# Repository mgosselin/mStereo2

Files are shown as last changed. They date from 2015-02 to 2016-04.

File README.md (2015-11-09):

# mStereo: revision 2

mStereo is a two-channel digital-to-analog converter (DAC) for audio. It is under active development.

## In this repository
    .
    ├── doc             # documents and media used in the README documentation
    ├── libraries       # kicad library files
    └── projects        # kicad project files
        ├── gerbers     # gerber files for PCB fabrication 
        └── bom         # bill of materials and supplementary information

## Using the contents of this repository

This repo is built and maintained with Linux users in mind.  Some contents are .pdf or plain text so the repo may be cloned and those files may be opened irrespective of the platform.  Users wishing to use the Kicad project and other Kicad files by cloning and/or forking the repo can do so in Linux: no support is implied for OSX or windows users (although generally, OSX users should experience no problems).  
    
## Scope

mStereo is intended to be used as a component in systems for playback of high-resolution digital audio stored on computers.

## Electrical Specifications

| Specification | Value | Unit |
| --- |:---: | ----- |
| +12 V supply current draw ** | 70 | mA |
| -12 V supply current draw ** | 69 | mA |
| +5 V supply current draw ** | 259 | mA |
| Output impedance *** | 20.3 | Ώ |
| Output DC voltage offset *** | ± 1 | mV |
| Output RMS voltage level at 0 dBFS *** | 4.000 | V |

**  _measured with each channel driving 100 Ώ resistive load_

*** _measured across + and - output terminals_

## Schematic

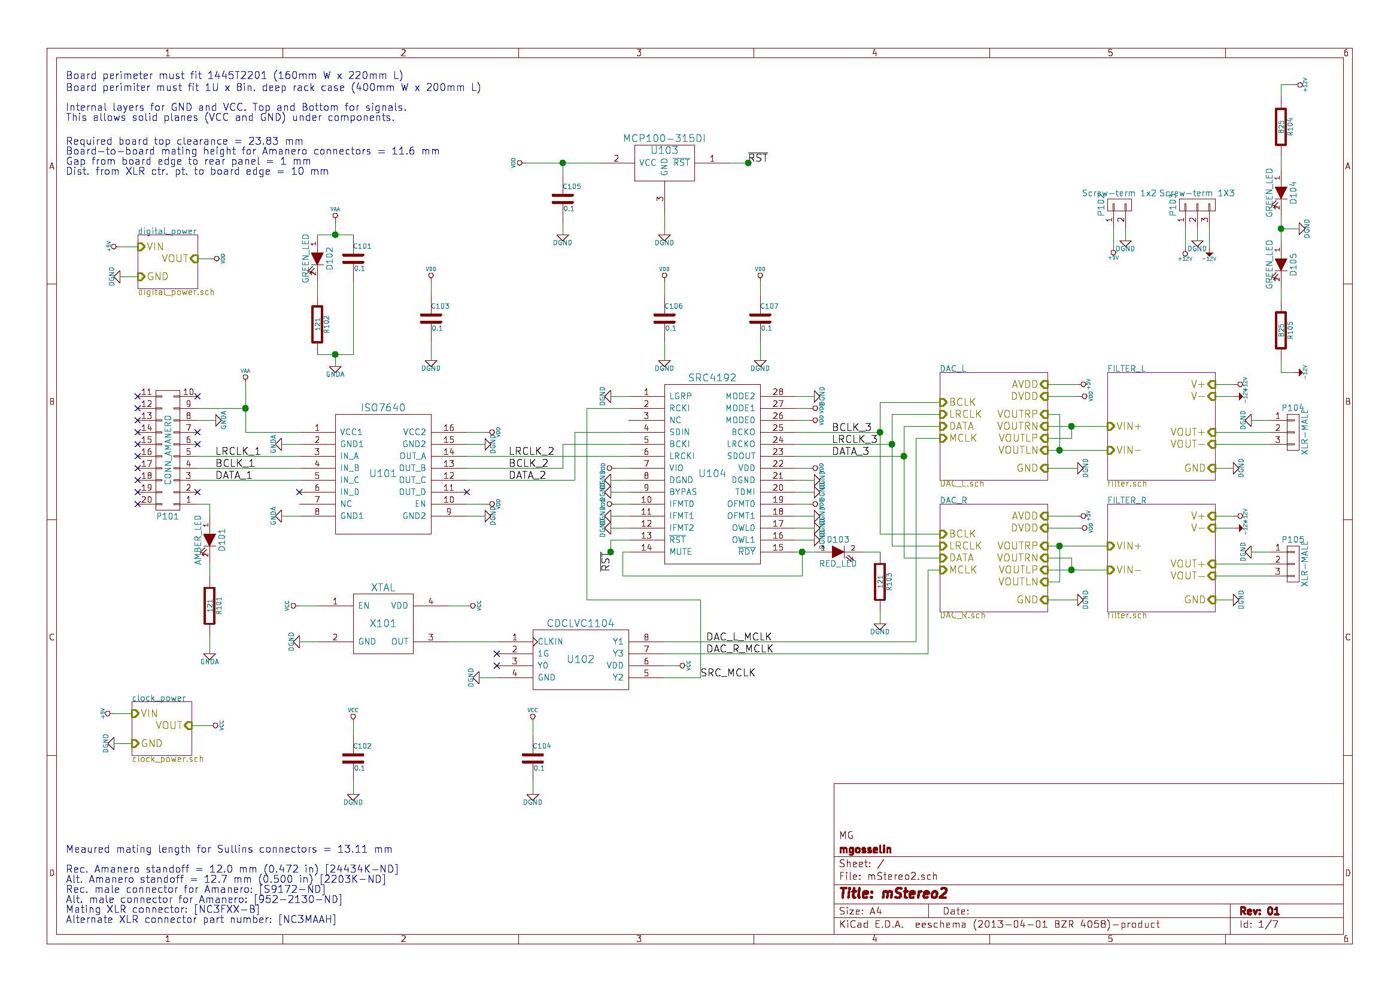
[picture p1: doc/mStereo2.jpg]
schematic


## Circuit Description

## Circuit Board

[Gerber files here](https://github.com/mgosselin/mStereo2/blob/master/projects/gerbers/).

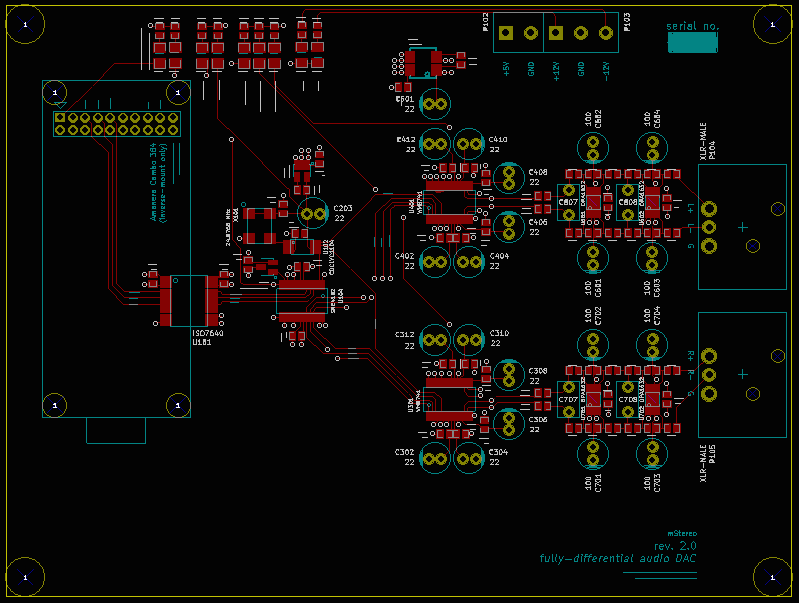
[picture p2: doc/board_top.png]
PCB_top


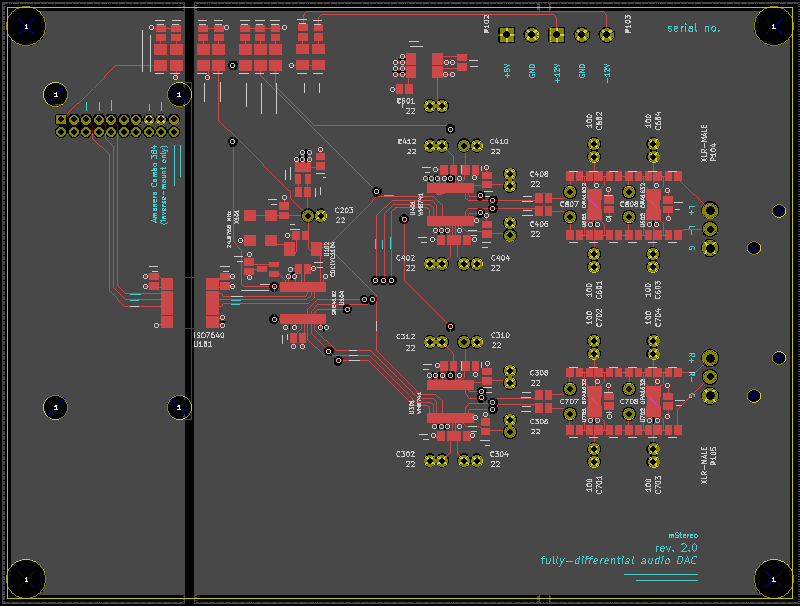
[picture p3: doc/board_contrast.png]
PCB_with_plates


## [BOM Page](https://github.com/mgosselin/mStereo2/blob/master/projects/bom)

## Assembly

## Ordering

At present, mStereo2 circuit boards (not populated) are available.  They may be obtained at-cost from me, by direct request.  

## History

mStereo is currently on revision 2.  Revision 1 is superceeded by revision 2, and while conceptually similar the hardware have little overlap.  Thus revision 1 documenation will no longer be updated and will remain accessible only by request.  

Since computers have become by far the most common way to exchange, store and playback audio recordings, the task remains to develop hardware to accompany computers and provide the best possible user experience. Since I am very serious about high-fidelity reproduction of audio recordings, developing my own hardware is challenging and rewarding on many fronts.

Practically, this means seeking the best possible hardware components (DAC ICs, oscillators, power supplies, etc.), integrating them, and ensuring their implementation permits their maximum specifications to be realized.

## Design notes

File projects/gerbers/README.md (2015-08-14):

# Gerber Files
All layers shown with edge-cut outline for easier viewing.

#### Copper Layers
Top Copper (signal traces, clock traces, clock power traces, component pads)
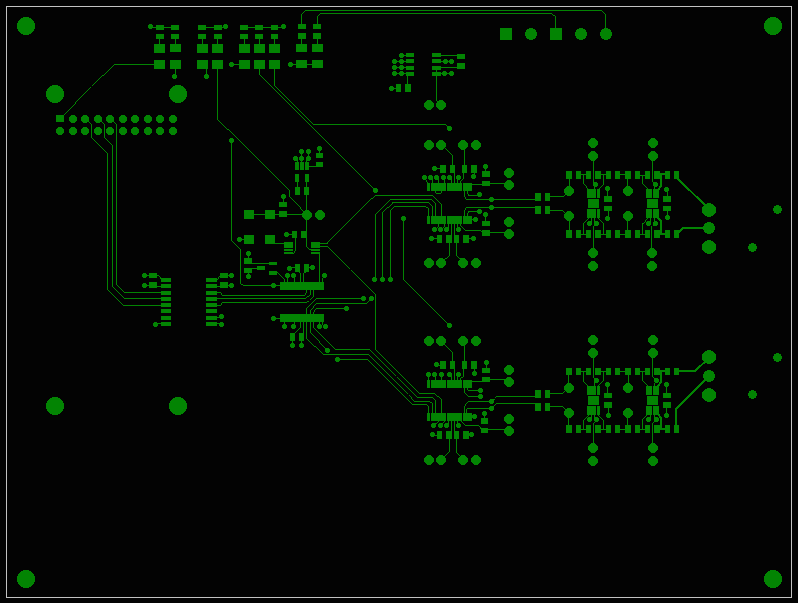
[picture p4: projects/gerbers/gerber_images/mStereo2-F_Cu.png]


Upper inner copper (planes [left-to-right]: USB ground, ground)
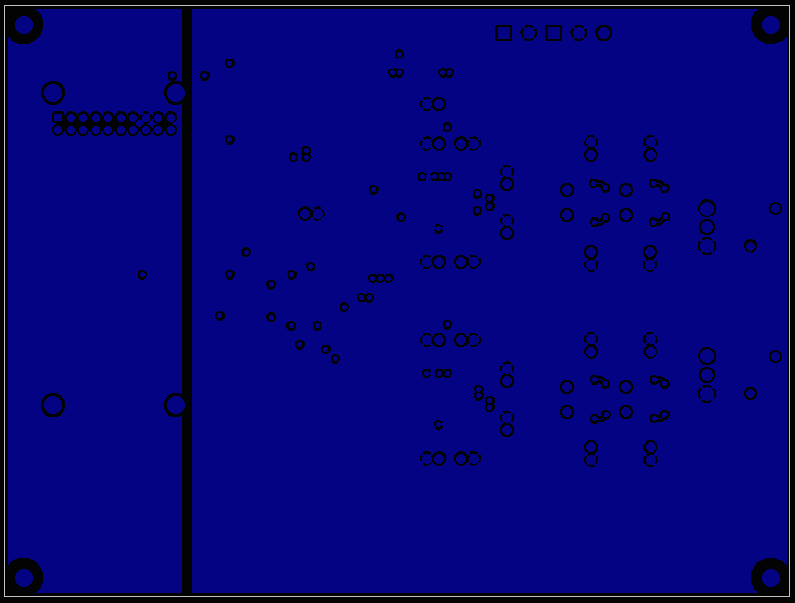
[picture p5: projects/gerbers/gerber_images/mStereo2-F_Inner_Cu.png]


Lower inner copper (planes [left-to-right]: USB power, +5VDC, +12VDC)
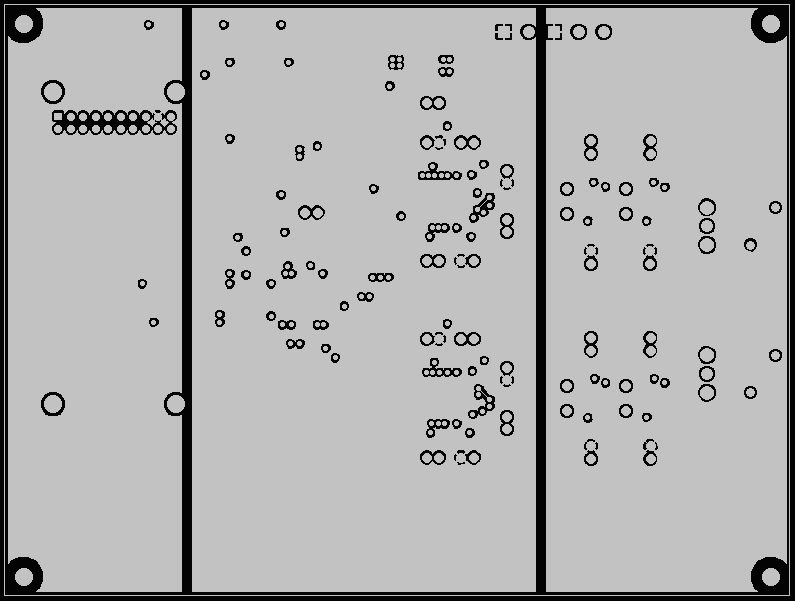
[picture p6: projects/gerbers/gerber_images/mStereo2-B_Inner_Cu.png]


Bottom copper (planes [left-to-right]: +3.3VDC, -12VDC)
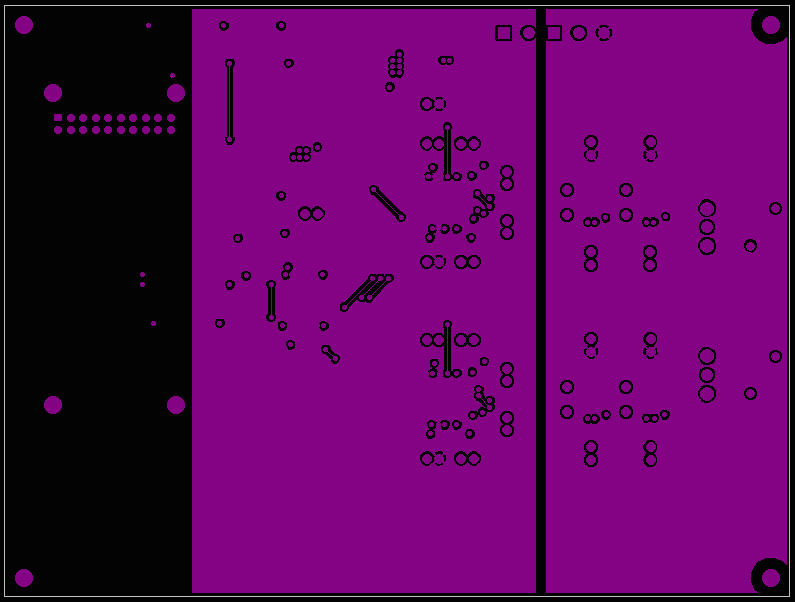
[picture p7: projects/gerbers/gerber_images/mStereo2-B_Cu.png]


#### Soldermask Layers
Top Soldermask
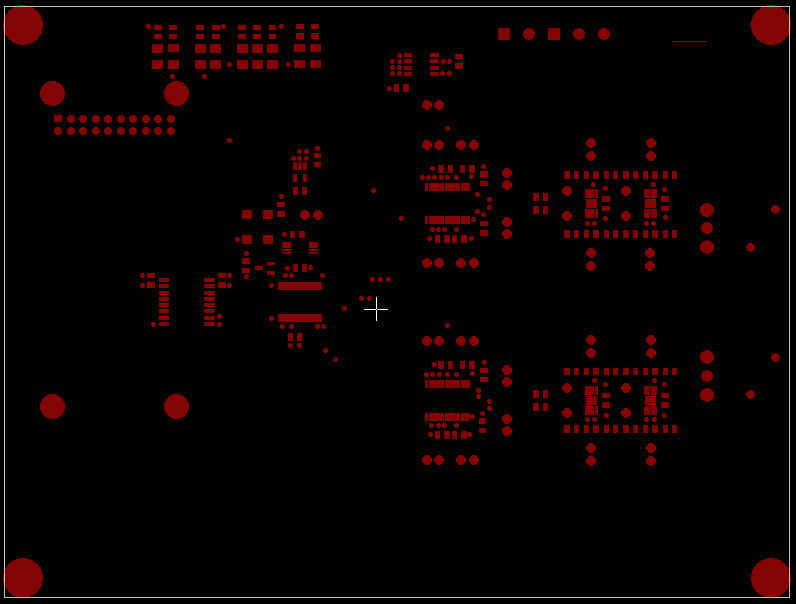
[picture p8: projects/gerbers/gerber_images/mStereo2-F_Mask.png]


Bottom Soldermask
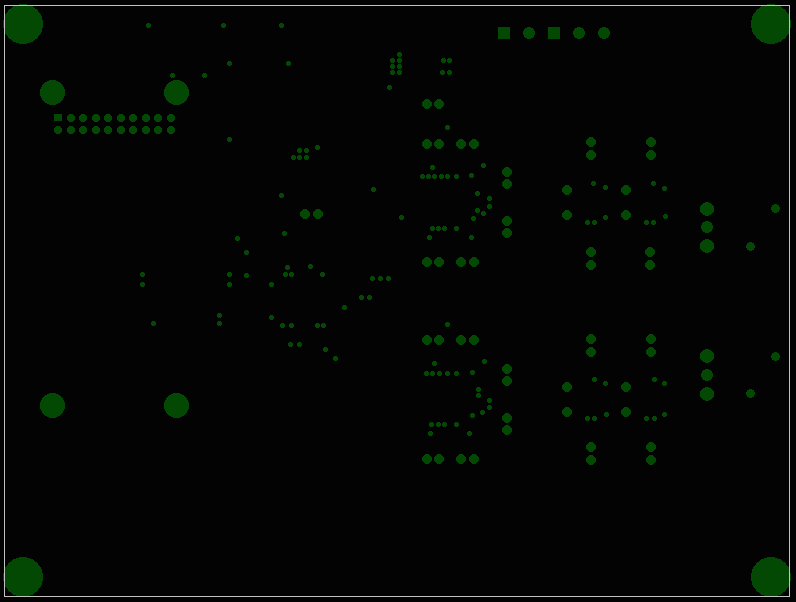
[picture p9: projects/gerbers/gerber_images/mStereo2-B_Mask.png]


#### Top Silkscreen Layer
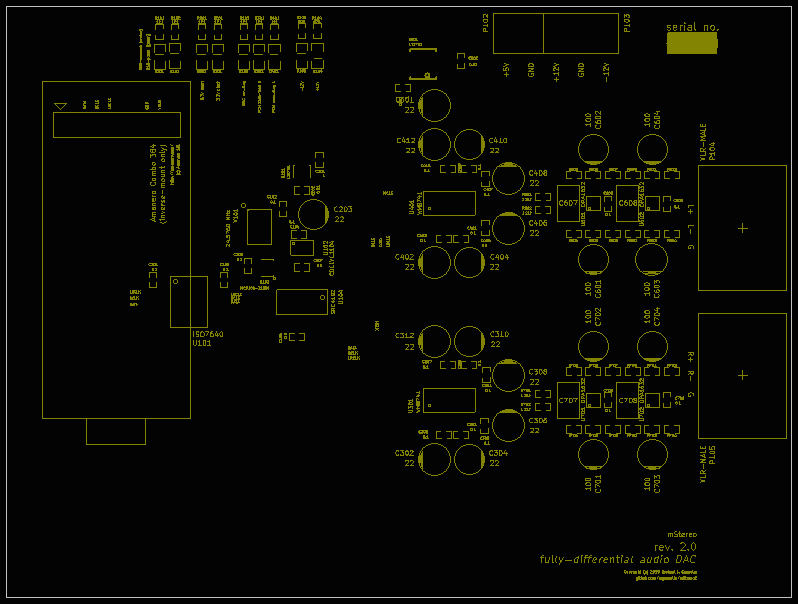
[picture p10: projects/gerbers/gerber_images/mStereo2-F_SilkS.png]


#### Drill holes
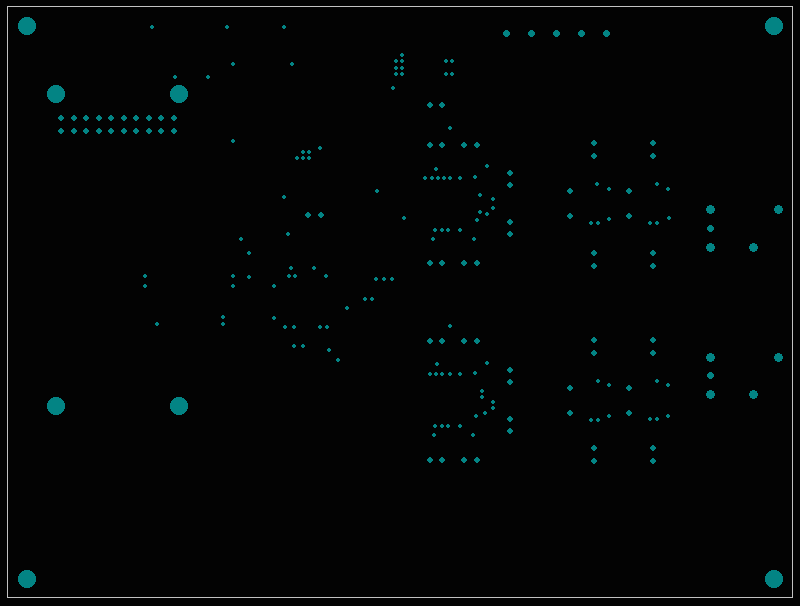
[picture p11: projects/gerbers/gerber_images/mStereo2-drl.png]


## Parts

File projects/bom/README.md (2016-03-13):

## BOM Notes

[The mStereo BOM](https://github.com/mgosselin/mStereo2/blob/master/projects/bom/mStereo2.csv) is best viewed in .CSV on a separate page.  Most vendors provide "BOM-upload tools" that prefer .CSV format.

#### 1. Circuit Board Support-Components
The BOM items are for populating the circuit board only.  Additional recommended hardware is as follows:
  
  1. A plastic insulation sheet to isolate the exposed pins on the bottom of the board (only needed if the PCB will be mounted less than 5mm from the chassis panel beneath it, and that chassis panel is metal).
  2. Standoffs
  3. Machine screws
  4. Hookup wire
  5. Heat shrink tubing

#### 2. Power supplies
A 12 VDC dual-rail regulated supply and a 5 VDC single-rail regulated supply are required.  The recommended supplies are the [AMB Labs](http://www.amb.org/audio/) [σ22](http://www.amb.org/audio/sigma22/) (a dual-rail linear regulated supply) and [σ11](http://www.amb.org/audio/sigma11/) (a single-rail linear regulated supply).  Both have been tested and are known to give excellent performance.  They are generally available on the [AMB Audio Shop](http://www.amb.org/shop/).  A slow-blow fuse rated for 200mA is recommended for these supplies.

Alternatives supplies may be used at your discretion.

BOMs for select [AMB Labs](http://www.amb.org/audio/) projects can be found [here](https://github.com/mgosselin/mStereo2/blob/master/projects/bom/AMB_Laboratories_Devices).

#### 3. Vendor Recommendations
#####Electronics:
  1. [Mouser](http://www.mouser.com/)
  2. [Digi-Key](http://www.digikey.com/)
  3. [Farnell](http://farnell.com/)

#####Mechanical Hardware:
  1. [McMaster-Carr](http://www.mcmaster.com/)
  2. [Amazon](http://www.amazon.com/)

#### 4. Output Filter / Buffer Design Considerations

#### 5. USB-to-I²S Conversion
As indicated in the [main README page](https://github.com/mgosselin/mStereo2), the mStereo circuit only accepts a valid I²S input as its source.  The circuit board is specifically designed around the [Combo 384](http://www.amanero.com/) module from Amanero SRL, which has a female USB type-A jack at its input.  Its mounting holes and connector fit properly with mStereo.  To use this module the following are needed:
 1. An Amanero Combo 384 module
 2. USB Cable, ideally with a ferrite choke such as Digi-Key part no. [1175-1417-ND](http://www.digikey.com/product-detail/en/102-1030-BL-F0100/1175-1417-ND/3782940)
 3. A USB panel mount jack, such as Neutrik [NAUSB-W-B](http://www.neutrik.com/en/multimedia/usb/nausb-w-b)*
 4. Standoffs (see table, below).  The board-to-board mating distance is 13.11 mm.
 5. M3 x 0.5 or #4-40 machine screws to go with standoffs

#####Combo 384 mounting information

| | Recommended Part No. | Alternate Part No. |
| --- |:---: | --- |
| Standoff (Female-Female) | [24434K-ND](http://www.digikey.com/product-search/en?keywords=24434K-ND) (12.0 mm, M3 thread)  | [2203K-ND](http://www.digikey.com/product-search/en?KeyWords=2203K-ND&WT.z_header=search_go) (0.500", 4-40 thread) |

| |  Female | Male |
| --- |:---: | --- |
| Connector |[S7078-ND](http://www.digikey.com/product-search/en?keywords=S7078-ND) ( _also found on the mStereo circuit board [BOM](https://github.com/mgosselin/mStereo2/blob/master/projects/bom/mStereo2.csv#L20)_ ) | [952-2130-ND](http://www.digikey.com/product-search/en?KeyWords=952-2130-ND&WT.z_header=search_go) |

**Ensure the USB cable and panel mount jack combination will work with the female USB-A-style jack on the Amanero Combo 384.*

#### 6. Enclosure and Mounting Considerations

  1. Hammond [1455Q1601](http://www.hammondmfg.com/pdf/1455Q1601.pdf) (PCB geometry and connector positioning fits this case perfectly, but without power supply)
  2. 1U standard rack-mount enclosures, from vendors such as [Hifi-2000](http://www.modushop.biz/site/index.php?route=product/category&path=20_27_61)
  3. Custom enclosures (DIY)

#####Key PCB and connector geometry

| Dimension | Quantity |
| --- |:---: |
| Board perimeter limits | 160 mm W x 120 mm L|
| Minimum clearance above top of PCB | 23.83 mm |
| Required gap from board edge to rear chassis panel | 1.0 mm |
| Required distance from XLR silkscreen centerpoint to chassis panel | 10 mm |
| Distance from XLR connector centerpoint to top of PCB | 12.5 mm |

#####XLR analog output connectors

The connectors listed below permit connection to the front or rear chassis panel with screws.  They should be fastened securely to the chassis panel so the force of inserting or pulling the mating XLR connector is not transferred to the PCB.  When received from the distributor, they come with straight, smooth-bore holes, which may be tapped with threads to permit easy attachment with machine screws to the chassis panel.  Use a UNC #4-40 tap or a metric size M3 tap and a tap wrench to tap threads in the appropriate plactes on these connectors.  

| Connector | Recommended Part No. | Alternate Part No. |
| --- | --- | --- |
| XLR chassis connector male |  Neutrik [NC3MAAH](http://www.neutrik.com/en/xlr/aa-series/nc3maah) | Neutrik [NC3MAAH-1](http://www.neutrik.com/en/xlr/aa-series/nc3maah-1) |
| Grounding Notes | _NOTE: with this connector, the PCB's signal ground plane (and therefore also the power supply ground) will connect to pin 1 only.  The signal ground plane will be isolated from the chassis panel and the mating connector.  It will ensure the chassis panel is connected to the mating connector shell for continuous sheilding._ |  _NOTE: with this connector the PCB's signal ground plane (and therefore also the power supply ground) will connect to the mating connector shell, the chassis panel, and pin 1, all at a common node._ |

The following female XLR cable connectors may be used to mate with the male chassis connectors on mStereo.  

| Connector | Recommended Part No. | Alternate Part No. |
| --- | --- | --- |
| XLR cable connector female | Neutrik [NC3FXX-B](http://www.neutrik.com/en/xlr/xx-series/nc3fxx-b) | Neutrik [NC3FXX](http://www.neutrik.com/en/xlr/xx-series/nc3fxx)|

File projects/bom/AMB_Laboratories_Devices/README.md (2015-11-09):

BOMs for select [AMB Labs](http://www.amb.org/audio/) projects, and others:
  * [ε24 power switch driver circuit](http://www.amb.org/audio/epsilon24/)
  * [σ22 regulated power supply](http://www.amb.org/audio/sigma22/)
  * Some support components for a Texas Instruments TPS7A4700-based power supply found on eBay

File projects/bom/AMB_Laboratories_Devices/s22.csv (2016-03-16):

Quantity | "Refs" | "Description" | "Supplier-PN" | "Manu-PN"
5 | R1 R2 R8 R9 R11 | RES 10.0K OHM 1/4W 1% AXIAL | 10.0KXBK-ND | MFR-25FBF52-10K
3 | R3 R16 R17 | RES 1.00K OHM 1/4W 1% AXIAL | 1.00KXBK-ND | MFR-25FBF52-1K
4 | R4 R5 R6 R7 | RES 100 OHM 1/4W 1% AXIAL | 100XBK-ND | MFR-25FBF52-100R
4 | R12 R13 R14 R15 | RES MO 2W .47 OHM 5% AXIAL | RSMF2JTR470CT-ND | RSMF2JTR470
6 | C1 C2 C3 C4 C16 C17 | CAP CER 220PF 100V 5% RADIAL | 399-4163-ND | C315C221J1G5TA
4 | C7 C8 C18 C19 | CAP FILM 1UF 10% 63VDC RADIAL | BC1622-ND | BFC237011105
4 | C5 C6 | CAP ALUM 1500UF 20% 50V RADIAL | 493-6907-ND | UHW1H152MHD6
5 | C9 C10 C13 C20 C21 | CAP ALUM 100UF 20% 63V RADIAL | 493-1936-ND | UPW1J101MPD
2 | C11 C12 | CAP ALUM 470UF 20% 63V RADIAL | 493-1948-ND | UPW1J471MHD
2 | C14 C15 | CAP FILM 3900PF 10% 400VDC RAD | BC1673-ND | BFC237051392
4 | D1 D2 D3 D4 | DIODE GEN PURP 200V 8A TO220AC | MUR820GOS-ND | MUR820G
1 | D5 | DIODE ZENER 12V 500MW DO35 | BZX55C12CT-ND | BZX55C12-TR
2 | D6 D7 | DIODE SCHOTTKY 40V 1A DO41 | 1N5819FSCT-ND | 1N5819
2 | CR1 CR2 | Current Regulator Diodes 2.2mA Curr Reg | 610-1N5306 | 1N5306
2 | CR3 CR4 | Current Regulator Diodes 4.7mA Curr Reg | 610-1N5314 | 1N5314
1 | LED | LED BLUE DIFF 3MM ROUND T/H | 751-1092-ND | TLHB4400
6 | Q1 Q3 Q4 Q9 Q10 Q12 | TRANS NPN 65V 0.1A TO-92 | BC546BTACT-ND | BC546BTA
6 | Q2 Q5 Q6 Q7 Q8 Q11 | TRANS PNP 65V 0.1A TO-92 | BC556BTACT-ND | BC556BTA
2 | Q13 Q14 | MOSFET N-CH 55V 17A TO-220AB | IRFZ24NPBF-ND | IRFZ24NPBF
2 | Q15 Q16 | MOSFET P-CH 55V 19A TO-220AB | IRF9Z34NPBF-ND | IRF9Z34NPBF
2 | - | CONN TERM BLOCK 3POS 5.08MM PCB | 277-1248-ND | 1729131
1 | - | CONN TERM BLOCK 2POS 5.08MM PCB | 277-1249-ND | 1729144
1 | - | XFRMR TOROIDAL 25VA CHAS MOUNT | 1295-1088-ND | 62063
1 | - | MOD PWR INLET COMPACT FILTER 10A | 817-1915-ND | FN281-10-06
4 | - | BOARD LEVEL HEATSINK 1-inch TO-220 | HS404-ND | 529702B02500G
4 | - | MOUNTING KIT TO-220 | HS417-ND | 4880G

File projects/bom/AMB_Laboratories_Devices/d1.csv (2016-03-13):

Quantity | Refs | Description | Supplier-PN | Manu-PN
2 | R1+ R1- | RES ARRAY 10 RES 1K OHM 11SIP | 4611X-101-102LF-ND | 4611X-101-102LF
2 | R2+ R2- | RES ARRAY 8 RES 47 OHM 9SIP | 4609X-101-470LF-ND | 4609X-101-470LF
2 | R5+ R5- | RES ARRAY 8 RES 47K OHM 9SIP | 4609X-101-473LF-ND | 4609X-101-473LF
2 | R3 R4 | miniature 1/8W resistor 3.3KΩ | S3.3KCACT-ND | RNMF14FTC3K30
2 | RS0L RS0R | Metal Film Resistors - Through Hole 1/10watt 1.4Kohms 1% 50ppm | 71-RN55C-F-1.4K | RN55C1401FB14
2 | RS1L RS1R | Metal Film Resistors - Through Hole 1/10watt 2.74Kohms 1% 50ppm | 71-RN55C-F-2.74K | RN55C2741FB14
2 | RS2L RS2R | Metal Film Resistors - Through Hole 1/10watt 5.11Kohms 1% 50ppm | 71-RN55C-F-5.11K | RN55C5111FB14
2 | RS3L RS3R | Metal Film Resistors - Through Hole 1/10watt 9.31Kohms 1% 50ppm | 71-RN55C9311F | RN55C9311FB14
2 | RS4L RS4R | Metal Film Resistors - Through Hole 1/10watt 15Kohms 1% 50ppm | 71-RN55C-F-15K | RN55C1502FB14
2 | RS5L RS5R | Metal Film Resistors - Through Hole 1/10watt 21Kohms 1% 50ppm | 71-RN55C-F-21K | RN55C2102FB14
2 | RS6L RS6R | Metal Film Resistors - Through Hole 1/10watt 24.3Kohms 1% 50ppm | 71-RN55C2432F | RN55C2432FB14
2 | RS7L RS7R | Metal Film Resistors - Through Hole 1/10watt 24.9Kohms 1% 50ppm | 71-RN55C-F-24.9K | RN55C2492FB14
2 | RP0L RP0R | Metal Film Resistors - Through Hole 1/10watt 422Kohms 1% 50ppm | 71-RN55C-F-422K | RN55C4223FB14
2 | RP1L RP1R | Metal Film Resistors - Through Hole 1/10watt 205Kohms 1% 50ppm | 71-RN55C2053F | RN55C2053FB14
2 | RP2L RP2R | Metal Film Resistors - Through Hole 1/10watt 97.6Kohms 1% 50ppm | 71-RN55C-F-97.6K | RN55C9762FB14
2 | RP3L RP3R | Metal Film Resistors - Through Hole 1/10watt 43.2Kohms 1% 50ppm | 71-RN55C-F-43.2K | RN55C4322FB14
2 | RP4L RP4R | Metal Film Resistors - Through Hole 1/10watt 16.5Kohms 1% 50ppm | 71-RN55C1652F | RN55C1652FB14
2 | RP5L RP5R | Metal Film Resistors - Through Hole 1/10watt 4.75Kohms 1% 50ppm | 71-RN55C-F-4.75K | RN55C4751FB14
2 | RP6L RP6R | Metal Film Resistors - Through Hole 1/10watt 649ohms 1% 50ppm | 71-RN55C-F-649 | RN55C6490FB14
2 | RP7L RP7R | Metal Film Resistors - Through Hole 1/10watt 16.2ohms 1% 50ppm | 71-RN55C-F-16.2 | RN55C16R2FB14
2 | RTL RTR | Metal Film Resistors - Through Hole 1/10watt 25.5Kohms 1% 50ppm | 71-RN55C2552F | RN55C2552FB14
2 | RGL RGR | RES 10 OHM 5W 5% AXIAL | PPC5W10.0CT-ND | AC05000001009JAC00
2 | C1 C3 | CAP POLYMER 470UF 20% 16V T/H | 565-3620-ND | APSG160ELL471MH08S
3 | C2+ C2- C4 | CAP CER 0.1UF 50V X7R RADIAL | 399-4264-ND | C320C104K5R5TA
2 | CGL CGR | CAP FILM 0.1UF 20% 300VAC RADIAL | P11116-ND | ECQ-U3A104MG
1 | L1 | FERRITE BEAD AXIAL LEAD 75 OHMS | 240-2438-1-ND | 28L0138-10R-10
2 | U1+ U1- | IC I/O EXPANDER I2C 8B 16DIP | 296-13106-5-ND | APCF8574AN
2 | U2+ U2- | TRANS 8NPN DARL 50V 0.5A 18DIP | ULN2803APG-ND | ULN2803APGCN
2 | LED+ LED- | LED BAR GRAPH 10SEG 590NM YLW | 754-1179-5-ND | DC10YWA
8 | K0-K7 | RELAY TELECOM DPDT 1A 4.5V | Z2143-ND | G6JU-2P-Y DC4.5
2 | - | CONN IC DIP SOCKET 16POS GOLD | ED90034-ND | 110-43-316-41-001000
2 | - | CONN IC DIP SOCKET 18POS GOLD | ED90035-ND | 110-43-318-41-001000
1 | J1 | CONN HEADER 6POS .100 R/A TIN | WM4304-ND | 0022053061
1 | J1 | CONN HOUS 6POS .100 W/RAMP/RIB | WM2004-ND | 0022013067
1 | J2 J3 | CONN HEADER 6POS .100 VERT TIN | WM4004-ND | 0022032061
1 | J2' J3' | CONN HEADER 6POS .100 STR TIN | WM8076-ND | 0901200126
1 | J2 J3 | Connector Receptacle 6 Position 0.100 (2.54mm) Tin Through Hole | WM4223-ND | 0901471106
1 | J4 | CONN HEADER 16POS .100 R/A TIN | 609-3356-ND | 68021-416HLF
1 | J5 | CONN RECEPT 16POS .100 RT/A DUAL | A34302-ND | 5-532956-2
2 | J4 J5 | [for ribbon cbl assly only] CONN HEADER 16POS R/A 10GOLD | MHE16E-ND | D2516-5002-AR
2 | J4 J5 | [for ribbon cbl assly only] CONN 16POS IDC SOCKET 10AU W/POL | MKC16E-ND | D89116-0131HK
2 | J4 J5 | [for ribbon cbl assly only] STRAIN RELIEF 16POS D89-SERIES | MESR16-ND | D3448-89116
1 | J4 J5 | [for ribbon cbl assly only] CBL RIBN 16COND 0.050 GRAY 5' | MC16G-5-ND | 3365/16 300SF
4 | INPUTL INPUTR OUTPUTL OUTPUTR | CONN HEADER 2POS .100 R/A TIN | WM4300-ND | 0022053021
4 | INPUTL INPUTR OUTPUTL OUTPUTR | CONN HOUS 2POS .100 W/RAMP/RIB | WM2000-ND | 0022013027
2 | INOUTL INOUTR | CONN HEADER 3POS .100 R/A TIN | WM4301-ND | 0022053031
2 | INOUTL INOUTR | CONN HOUS 3POS .100 W/RAMP/RIB | WM2001-ND | 0022013037
20 | - | CONN TERM FEMALE 22-30AWG TIN | WM1114-ND | 0008500114
1 | JP1A+ JP1B+ JP1C+ JP1A- JP1B- JP1C- JP2 JP3 | CONN HEADER .100 SINGL STR 36POS | S1011E-36-ND | PBC36SAAN
10 | - | CONN JUMPER SHORTING GOLD FLASH | S9001-ND | SPC02SYAN
4 | - | HEX STANDOFF M3 ALUMINUM 12MM | 36-24434-ND | 24434

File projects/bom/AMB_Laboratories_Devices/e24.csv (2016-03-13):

Quantity | "Refs" | "Description" | "Supplier-PN" | "Manu-PN"
1 | R1 | 470K 1/8W miniature resistor | S470KQCT-ND | CFM14JT470K
1 | R2 | 2.2MΩ 1/8W miniature resistor | S2.2MQCT-ND | CFM14JT2M20
1 | R3 | 2.2KΩ 1/8W miniature resistor | S2.2KQCT-ND | CFM14JT2K20
1 | R5 | 330KΩ 1/8W miniature resistor | S330KQCT-ND | CFM14JT330K
1 | R6 | 10KΩ 1/8W miniature resistor | S10KQCT-ND | CFM14JT10K0
1 | C1 | 470µF 25V electrolytic capacitor (8mm diameter 3.5mm lead pitch) | P12389-ND | EEU-FM1E471L
1 | C2 | 10µF 25V dipped tantalum capacitor (2.5mm lead pitch) | 399-3565-ND | T350E106K025AT
1 | C3 | 0.33µF 50V Z5U multilayer ceramic capacitor (2.5mm lead pitch) | 399-4299-ND | C320C334M5U5TA
1 | D1 | RECTIFIER BRIDGE 1.5A 100V WOG | W01G-E4/51GI-ND | W01G-E4/51
1 | D3 | 1N4148 small signal diode (DO-35) | 1N4148FS-ND | 1N4148
1 | Q2 | 2N3904 NPN transistor (TO-92) | 2N3904FS-ND | 2N3904BU
1 | Q3 | MOSFET N-CH 55V 18A TO-220AB | IRLZ24NPBF-ND | IRLZ24NPBF
1 | U1 | IC REG LDO 12V 1.5A TO220 | 497-12406-ND | L7812CV-DG
1 | - | RELAY GEN PURPOSE SPST 20A 12V | 255-4179-ND | JM1AN-ZTM-DC12V-F
1 | - | XFRMR TOROIDAL 1.6VA CHAS MOUNT | 1295-1018-ND | 62002
1 | - | SWITCH PUSH SPST-NO 0.05A 24V | 708-1453-ND | MPI002/TERM/WH

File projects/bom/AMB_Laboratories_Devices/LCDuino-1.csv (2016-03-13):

Quantity | "Refs" | "Description" | "Supplier-PN" | "Manu-PN"
1 | R1 | RES 10K OHM 1/4W 1% AXIAL | S10KCACT-ND | RNMF14FTC10K0
2 | R2 R3 | RES 1K OHM 1/4W 1% AXIAL | S1KCACT-ND | RNMF14FTC1K00
1 | VR1 | TRIMMER 10K OHM 0.5W TH | 490-2875-ND | PV36W103C01B00
1 | - | Potentiometers 16mm 100K ROTARY 3B TAPER | 688-RK16812MG099 | RK16812MG099
1 | C1 | CAP ALUM 100UF 20% 6.3V RADIAL | P958-ND | ECE-A0JKS101
4 | C2 C3 C4 C5 | CAP CER 0.1UF 50V X7R RADIAL | 399-4264-ND | C320C104K5R5TA
1 | C6 | CAP TANT 1UF 25V 10% RADIAL | 478-1834-ND | TAP105K025SCS
1 | Cs | 0.022F 5.5volts Radial Super Cap | 80-FR0H223ZF | FR0H223ZF
1 | U1 | Atmel ATmega328P-PU pre-flashed with bootloader and Volu-Master firmware | AMB audio shop | AMB audio shop
1 | U1' | IC MCU 8BIT 32KB FLASH 28DIP | ATMEGA328P-PU-ND | ATMEGA328P-PU
1 | U2 | IC RTC CLK/CALENDAR SER 8-DIP | DS1302+-ND | DS1302+
1 | U3 | IC I/O EXPANDER I2C 8B 18DIP | MCP23008-E/P-ND | MCP23008-E/P
1 | U4 | IC IR RCVR MOD 38KHZ DOME RADIAL | 751-1386-5-ND | TSOP34838
1 | U5 | IC MOTOR DRIVER PAR 16-DIP | 497-2936-5-ND | L293D
1 | X1 | CER RESONATOR 16.0MHZ | 490-1214-ND | CSTLS16M0X55-B0
1 | X2 | Crystal 32.7680kHz 20ppm 6pF 50 kOhm -10°C - 60°C Through Hole Radial | 728-1000-ND | VT200F-6PF20PPM
1 | LED13 | LED YELLOW DIFF 3MM ROUND T/H | TLHY4401-ND | TLHY4401
1 | LEDP | LED GRN DIFF 3MM ROUND T/H | 160-1142-ND | LTL-4231N
1 | SW1 | SWITCH TACTILE SPST-NO 0.05A 24V | SW400-ND | B3F-1000
1 | PWR/CFG switch | SWITCH PUSH SPST-NO 0.05A 24V | 708-1453-ND | MPI002/TERM/WH
1 | SSR | RELAY SSR 280VAC/5A3-32VDC ZC | CC1762-ND | CL240D05
1 | - | CONN IC DIP SOCKET 28POS TIN | ED90054-ND | 110-44-328-41-001000
1 | - | CONN IC DIP SOCKET 8POS TIN | ED90048-ND | 110-44-308-41-001000
1 | - | CONN IC DIP SOCKET 18POS TIN | ED90051-ND | 110-44-318-41-001000
1 | - | CONN IC DIP SOCKET 16POS TIN | ED90050-ND | 110-44-316-41-001000
2 | J1 J2 | CONN HEADER VERT .100 6POS 30AU | A26550-ND | 87220-6
2 | J1' J2' | Connector Receptacle 6 Position 0.100 Gold | A26418-ND | 534237-4
2 | J3 J4 | CONN HEADER 6POS .100 VERT TIN | WM4204-ND | 0022232061
2 | J3 J4 | CONN HOUS 6POS .100 W/RAMP/RIB | WM2004-ND | 0022013067
2 | J5 J6 | CONN HEADER 2POS .100 VERT TIN | WM4200-ND | 0022232021
2 | J5 J6 | CONN HOUS 2POS .100 W/RAMP/RIB | WM2000-ND | 0022013027
1 | J9 | CONN HEADER 5POS .100 VERT TIN | WM4203-ND | 0022232051
1 | J9 | CONN HOUS 5POS .100 W/RAMP/RIB | WM2003-ND | 0022013057
30 | - | CONN TERM FEMALE 22-30AWG TIN | WM1114-ND | 0008500114
1 | - | CABLE USB EMBD UART 3.3V .1inch HDR | 768-1015-ND | TTL-232R-3V3
1 | LCD | LCD MOD CHAR 2X16 WHT TRANSFL | NHD-0216K1Z-FSW-FBW-L-ND | NHD-0216K1Z-FSW-FBW-L
4 | SPACER | ROUND SPACER M3 BRASS 3MM | 952-1560-ND | R30-6010302
4 | STANDOFF | HEX STANDOFF M3 BRASS 13MM | 952-1504-ND | R30-3001302

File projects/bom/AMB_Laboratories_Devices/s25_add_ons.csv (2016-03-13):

Quantity | "Refs" | "Description" | "Supplier-PN" | "Manu-PN"
1 | R1 | RES 220 OHM 1/4W 1% AXIAL | S220CACT-ND | RNMF14FTC220R
1 | C2 | CAP ALUM 1000UF 20% 35V RADIAL | 493-6822-ND | UHW1V102MHD
1 | U1 | IC REG LDO 5V 1.5A TO220AB | 497-1404-5-ND | L4940V5
1 | U1' | IC REG LDO 5V 1A TO220-3 | LM7805CT-ND | LM7805CT
1 | - | XFRMR TOROIDAL 10VA CHAS MOUNT | 1295-1052-ND | 62041

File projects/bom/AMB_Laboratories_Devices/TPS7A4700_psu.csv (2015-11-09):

Quantity | "Refs" | "Description" | "Supplier-PN" | "Manu-PN"
3 | - | CONN TERM BLOCK 2POS 5.08MM PCB | 277-1247-ND | 1729128
3 | - | TERM BLOCK PCB 2POS 7.5MM GREEN | 277-6235-ND | 1717020
3 | - | HEAT SINK 15MM X 15MM X 9.5MM | ATS1263-ND | ATS-55150D-C2-R0

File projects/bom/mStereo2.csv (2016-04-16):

Quantity | "Supplier" | "Supplier-PN" | "Manu" | "Manu-PN" | "Refs"
1 | Digi-Key | LT1761ES5-3.3#TRMPBFCT-ND | Linear Technology | LT1761ES5-3.3#TRMPBF | U201
5 | Digi-Key | 160-1423-1-ND | Lite-On | LTST-C171GKT | D104 D105 D102 D201 D501
2 | Digi-Key | RNCP0805FTD825RCT-ND | Stackpole | RNCP0805FTD825R | R104 R105
1 | Digi-Key | LT1763CS8-3.3#PBF-ND | Linear Technology | LT1763CS8-3.3#PBF | U501
3 | Digi-Key | 160-1427-1-ND | Lite-On | LTST-C171KRKT | D103 D301 D401
1 | Digi-Key | 492-1695-1-ND | Bivar | SM0805AC | D101
8 | Digi-Key | P16291-ND | Panasonic | 16SEPC100M | C601 C602 C603 C604 C701 C702 C703 C704
7 | Digi-Key | RNCP0805FTD121RCT-ND | Stackpole | RNCP0805FTD121R | R102 R101 R103 R201 R501 R401 R301
14 | Digi-Key | P16405CT-ND | Panasonic | 32SEPF22M+TSS | C203 c301 c302 c303 c304 c305 c306 C402 C404 C406 C408 C410 C412 C501
23 | Digi-Key | 445-8183-1-ND | TDK | CGJ4J2X7R1C104K125AA | C101 C103 C104 C102 C106 C107 C105 C302 C304 C303 C305 C306 C301 C403 C407 C405 C409 C411 C401 C605 C606 C705 C706
1 | Digi-Key | 277-1247-ND | Phoenix Contact | 1729128 | P102
1 | Digi-Key | MCP100T-315I/TTCT-ND | Microchip | MCP100T-315I/TT | U103
4 | Digi-Key | 399-7715-ND | Kemet | PFR5471H100J11L4BULK | C607 C608 C707 C708
1 | Digi-Key | 296-27549-1-ND | Texas Instruments | CDCLVC1104PWR | U102
1 | Digi-Key | 77-1248-ND | Phoenix Contact | 1729131 | P103
8 | Digi-Key | 985-1307-1-ND | Welwyn | PCF0805R-2K49BT1 | R605 R611 R606 R612 R705 R711 R706 R712
4 | Digi-Key | 296-17008-ND | Texas Instruments | OPA1632DGN | U601 U602 U701 U702
2 | Digi-Key | 445-9190-1-ND | TDK | CGJ4J3X7R2D103K125AA | C202 C502
1 | Digi-Key | S7078-ND | Sullins | PPTC102LFBN-RC | P101
16 | Digi-Key | 985-1303-1-ND | Welwyn | PCF0805R-1K21BT1 | R601 R603 R607 R609 R602 R604 R608 R610 R701 R703 R707 R709 R702 R704 R708 R710
1 | Digi-Key | 296-29703-5-ND | Texas Instruments | ISO7640FMDW | U101
2 | Digi-Key | 445-8189-1-ND | TDK | CGJ4J2X7R1C105K125AA | C201 C503
1 | Digi-Key | 296-15234-5-ND | Texas Instruments | SRC4192IDB | U104
4 | Digi-Key | MCU0805-0.0-ZZCT-ND | Vishay Beyschlag | MCU08050Z0000ZP500 | R613 R614 R713 R714
1 | Digi-Key | 535-9318-1-ND | Abracon LLC | ASV-24.576MHZ-EJ-T | X101
2 | Digi-Key | WM8741GEDS/RVCT-ND | Cirrus Logic Inc. | WM8741GEDS/RV | U301 U401
2 | Mouser | 568-NC3MAAH | Neutrik | NC3MAAH | P104 P105

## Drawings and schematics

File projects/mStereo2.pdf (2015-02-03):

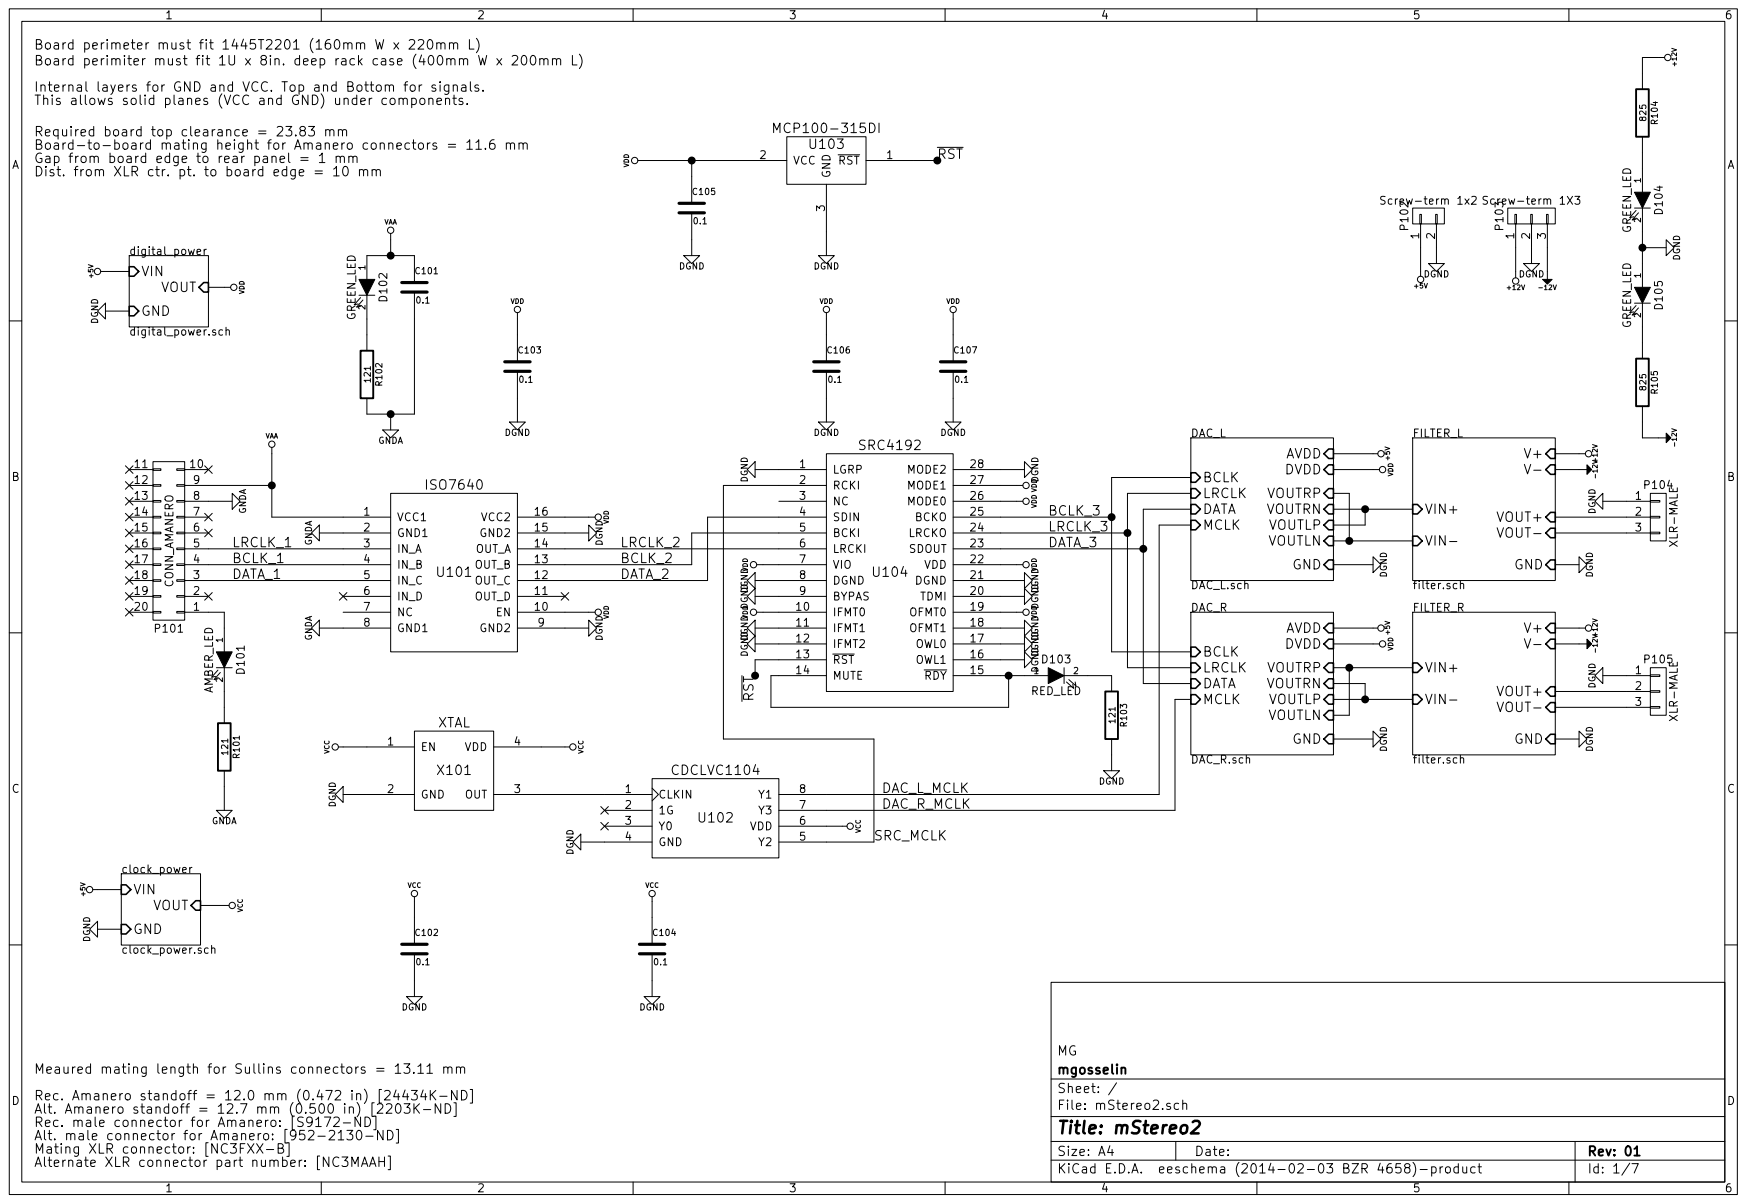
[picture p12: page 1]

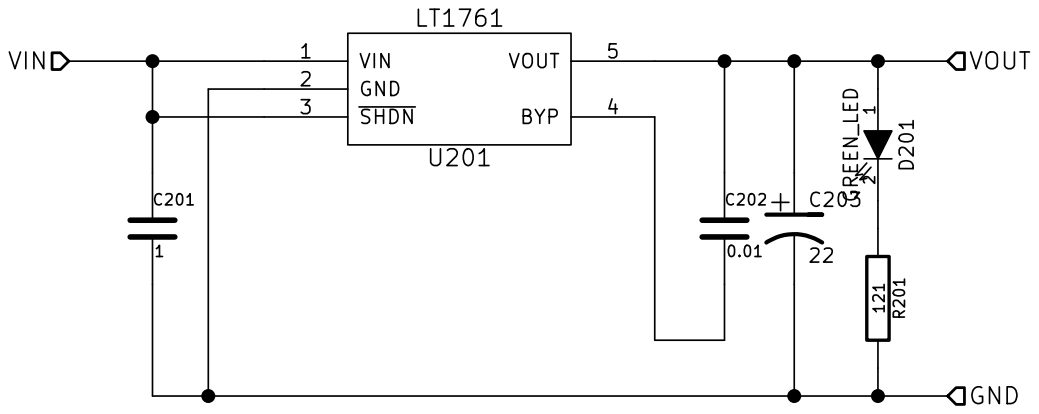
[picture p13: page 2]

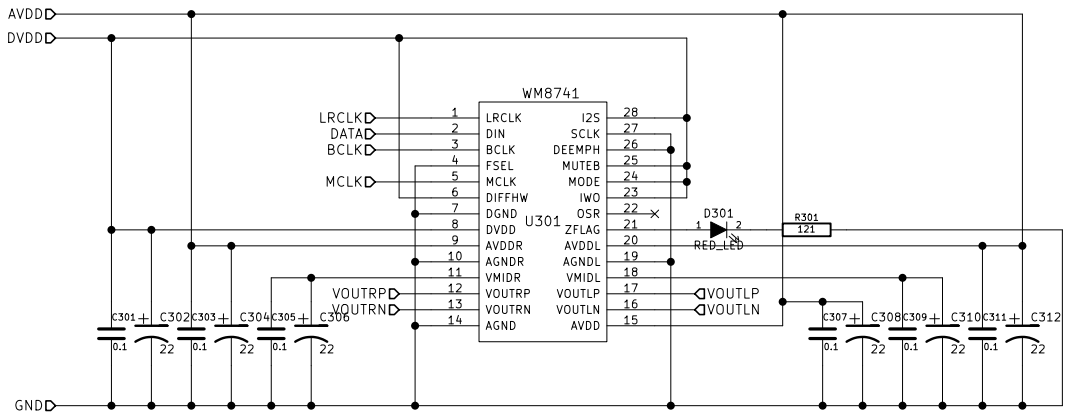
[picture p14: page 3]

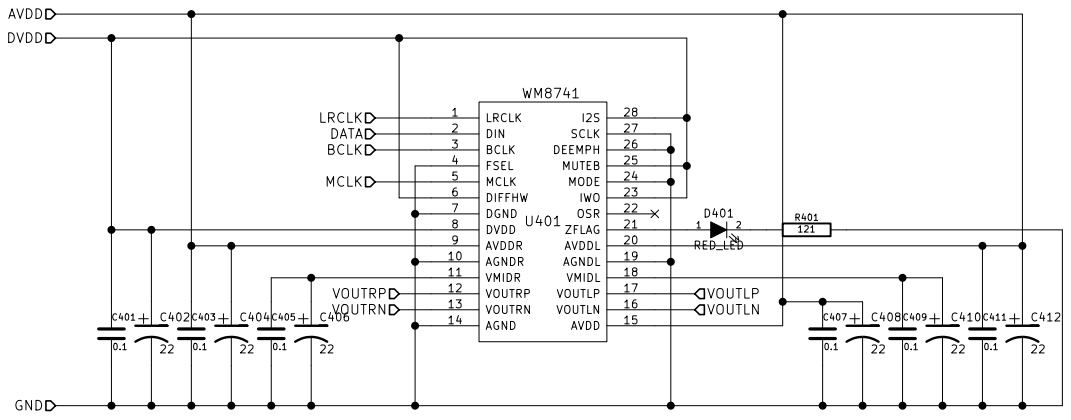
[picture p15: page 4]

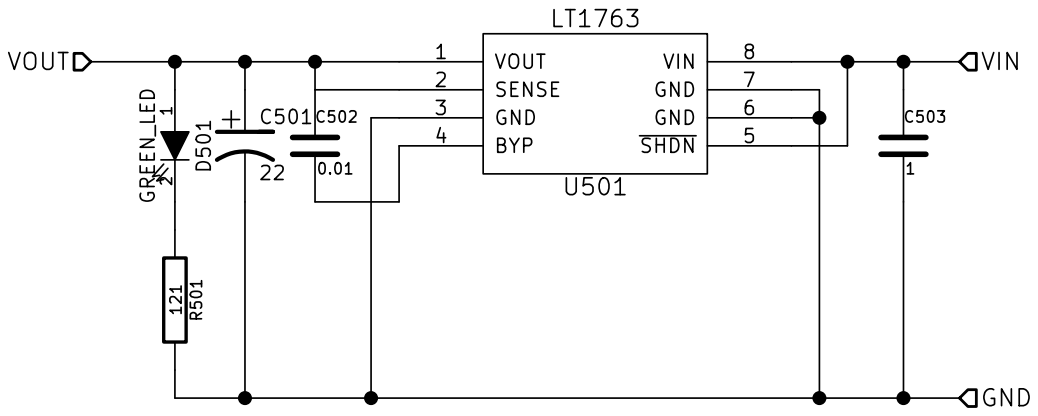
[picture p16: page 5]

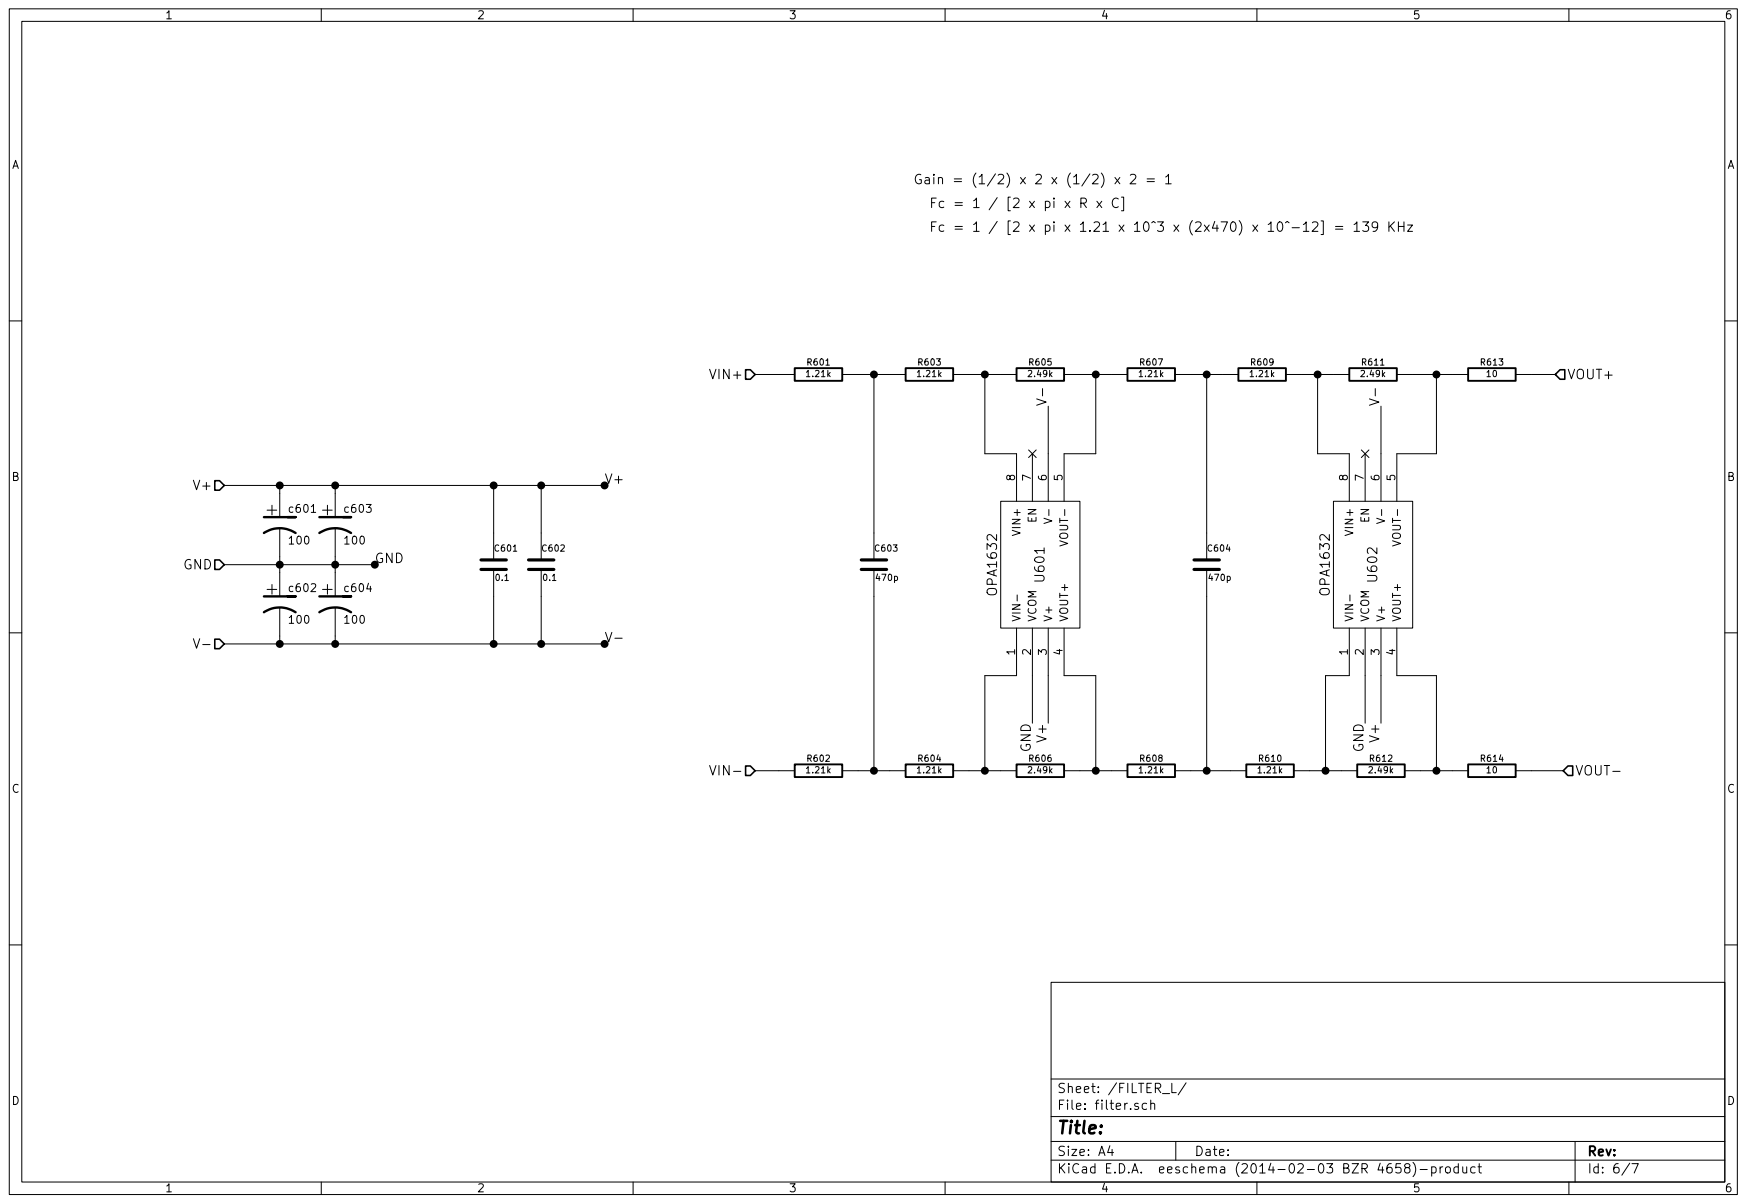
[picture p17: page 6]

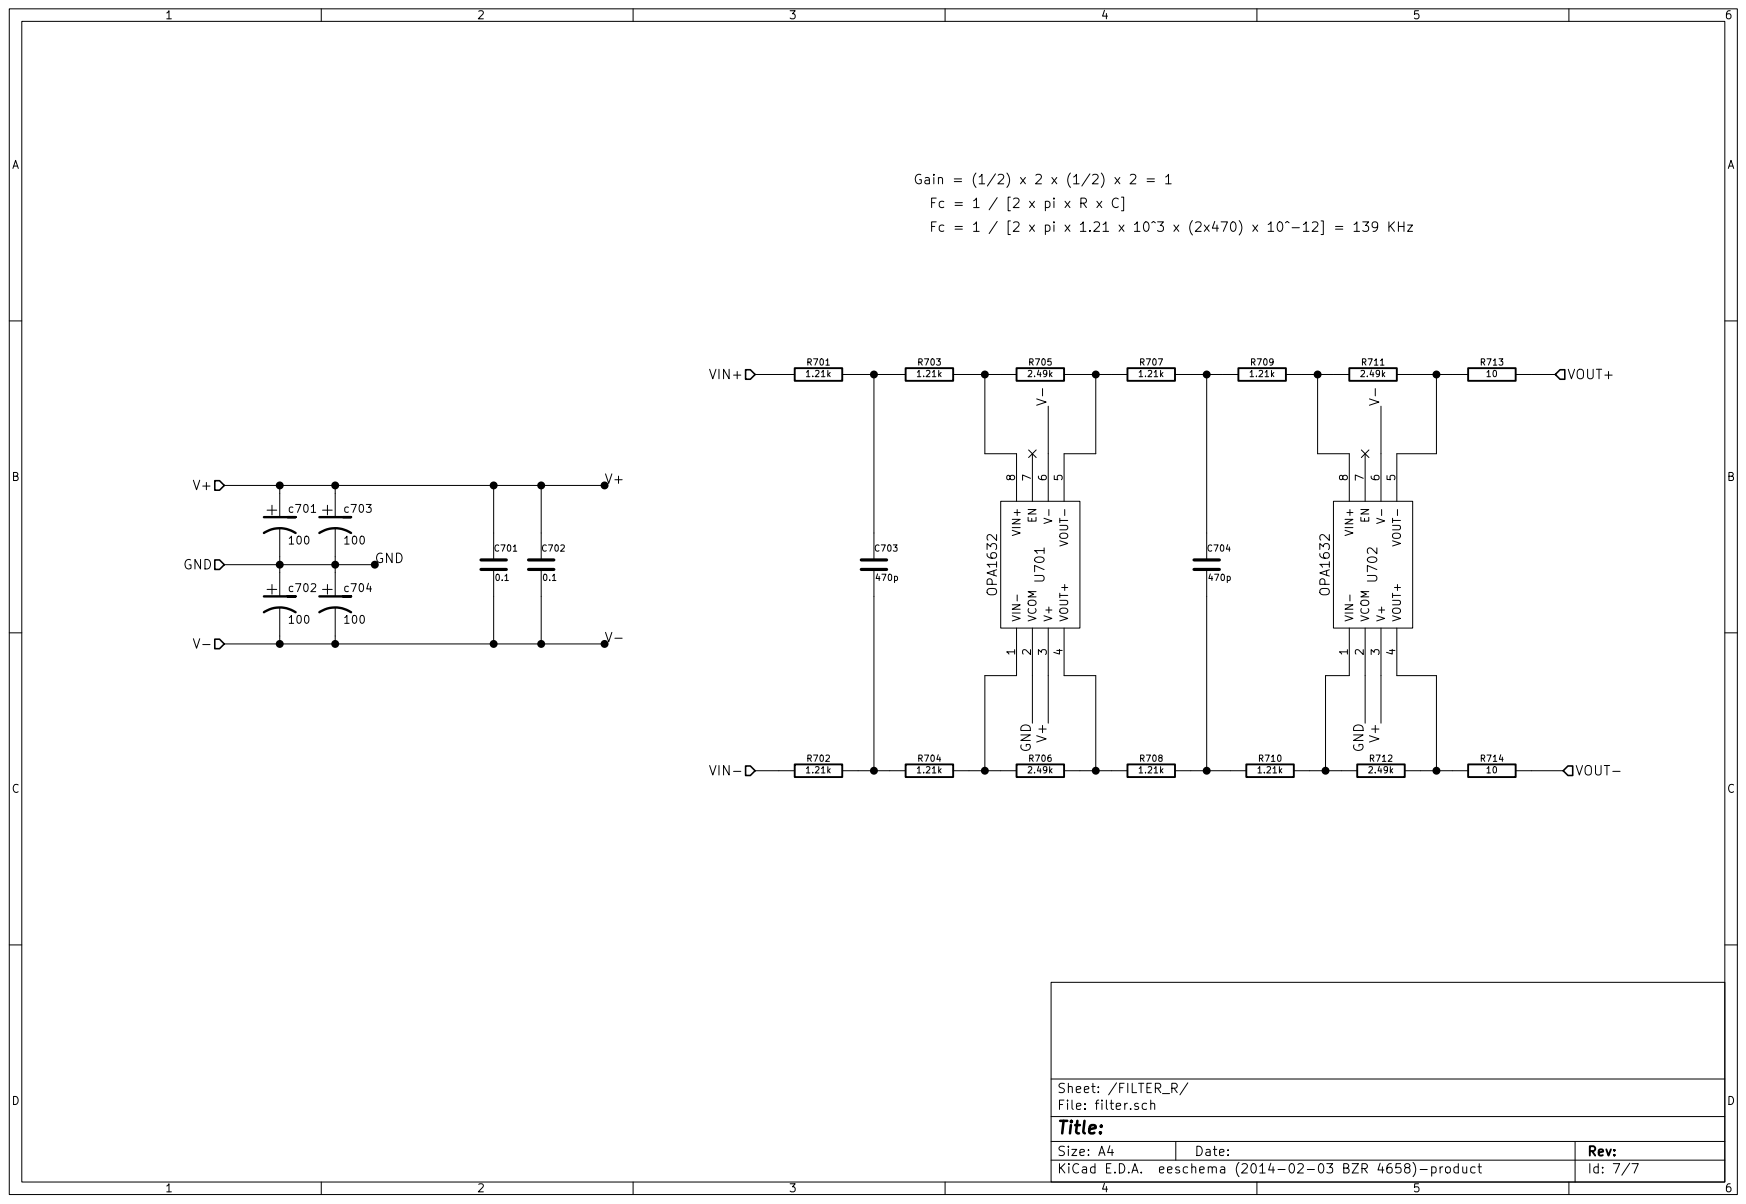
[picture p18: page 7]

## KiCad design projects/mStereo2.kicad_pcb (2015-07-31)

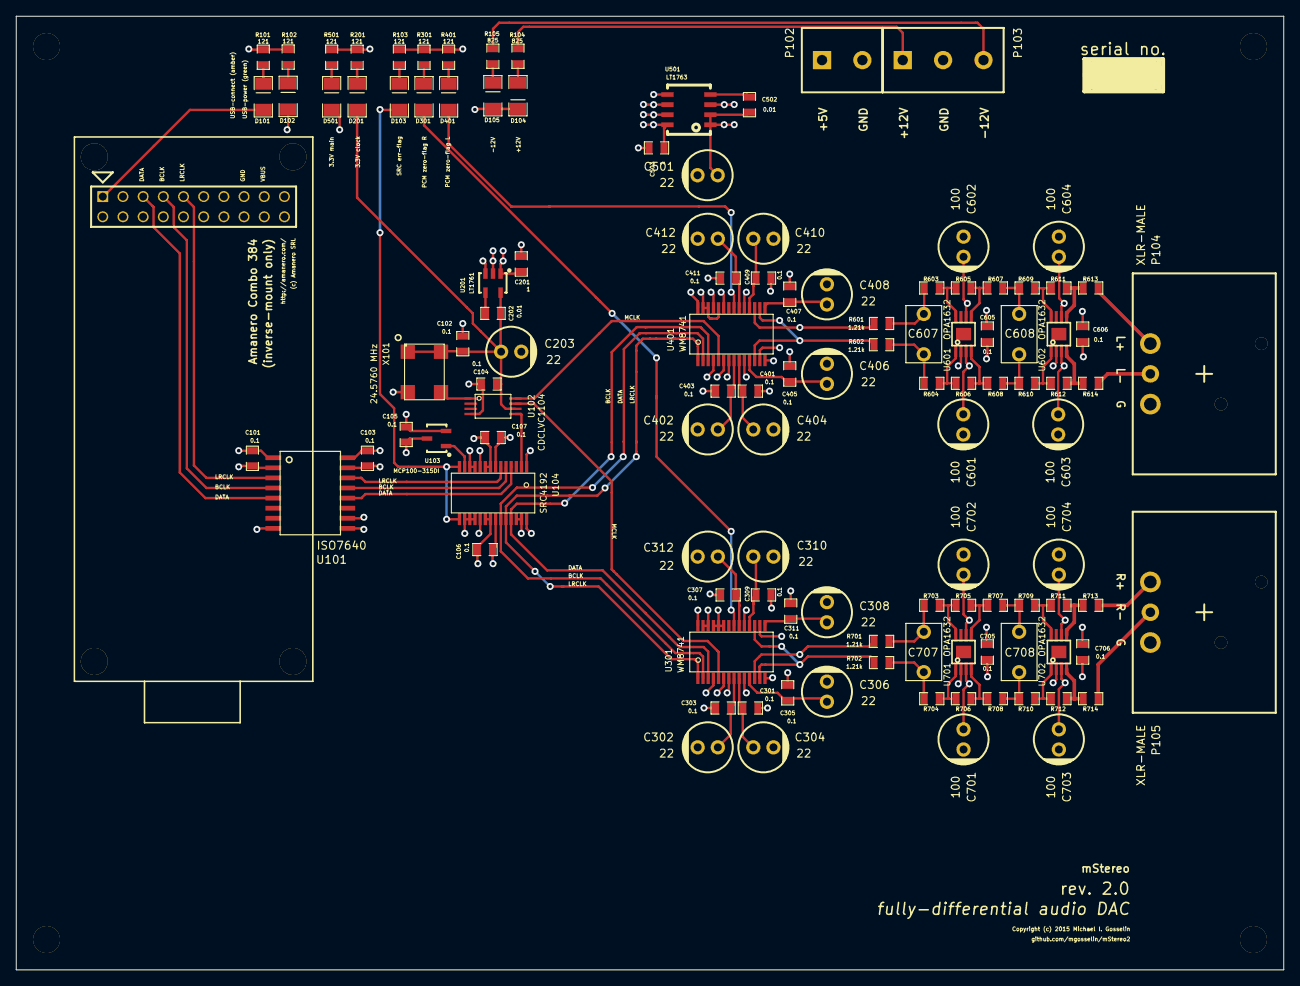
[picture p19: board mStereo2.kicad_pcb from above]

Board: 4 copper layers, 159.5 x 120.0 mm, 125 parts (1 on the bottom side), 73 nets.

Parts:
C101, C102, C103, C104, C105, C106, C107, C301, C303, C305, C307, C309, C311, C401, C403, C405, C407, C409, C411, C605, C606, C705, C706: 0.1; 0805
C201, C503: 1; 0805
C202, C502: 0.01; 0805
C203, C302, C304, C306, C308, C310, C312, C402, C404, C406, C408, C410, C412, C501: 22; CAP-POL-2.54-mm
C601, C602, C603, C604, C701, C702, C703, C704: 100; CAP-POL-2.54-mm
C607, C608, C707, C708: 470p; CAP-BOX-5.00-mm
D101: USB-connect (amber); 1206_LED
D102: USB-power (green); 1206_LED
D103: SRC err-flag; 1206_LED
D104: +12V; 1206_LED
D105: -12V; 1206_LED
D201: 3.3V clock; 1206_LED
D301: PCM zero-flag R; 1206_LED
D401: PCM zero-flag L; 1206_LED
D501: 3.3V main; 1206_LED
P101: CONN_AMANERO; 2x10_female
P102: Screw-term 1x2; 1x2
P103: Screw-term 1X3; 1x3
P104, P105: XLR-MALE; NC3MAAH-1
R101, R102, R103, R201, R301, R401, R501: 121; 0805
R104, R105: 825; 0805
R601, R602, R603, R604, R607, R608, R609, R610, R701, R702, R703, R704, R707, R708, R709, R710: 1.21k; 0805
R605, R606, R611, R612, R705, R706, R711, R712: 2.49k; 0805
R613, R614, R713, R714: 10; 0805
U101: ISO7640; SOIC-16-W
U102: CDCLVC1104; TSSOP-8
U103: MCP100-315DI; SOT-23-3
U104: SRC4192; TSSOP-28
U201: LT1761; SOT-23-5
U301, U401: WM8741; TSSOP-28
U501: LT1763; SOIC-8
U601, U602, U701, U702: OPA1632; MSOP-8-PWP
X101: 24.5760 MHz; XTAL-5x7mm
mounting_m3, mounting_m3#2, mounting_m3#3, mounting_m3#4, mounting_m3#5, mounting_m3#6, mounting_m3#7, mounting_m3#8: VAL**; mounting_m3

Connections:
+5V: C201.1, C303.1, C304.1, C307.1, C308.1, C311.1, C312.1, C403.1, C404.1, C407.1, C408.1, C411.1, C412.1, C503.1, P102.1, U201.1, U201.3, U301.9, U301.15, U301.20, U401.9, U401.15, U401.20, U501.5, U501.8
+12V: C601.1, C603.1, C605.1, C606.1, C701.1, C703.1, C705.1, C706.1, P103.1, R104.1, U601.3, U602.3, U701.3, U702.3
-12V: C602.2, C604.2, C605.2, C606.2, C702.2, C704.2, C705.2, C706.2, P103.3, R105.2, U601.6, U602.6, U701.6, U702.6
/BCLK_1: P101.4, U101.4
/BCLK_2: U101.13, U104.5
/DAC_L/BCLK: U104.25, U301.3, U401.3
/DAC_L/DATA: U104.23, U301.2, U401.2
/DAC_L/LRCLK: U104.24, U301.1, U401.1
/DAC_L/MCLK: U102.8, U401.5
/DAC_R/MCLK: U102.7, U301.5
/DATA_1: P101.3, U101.5
/DATA_2: U101.12, U104.4
/FILTER_L/VIN+: R601.1, U401.13, U401.17
/FILTER_L/VIN-: R602.1, U401.12, U401.16
/FILTER_L/VOUT+: P104.2, R613.2
/FILTER_L/VOUT-: P104.3, R614.2
/FILTER_R/VIN+: R701.1, U301.12, U301.16
/FILTER_R/VIN-: R702.1, U301.13, U301.17
/FILTER_R/VOUT+: P105.2, R713.2
/FILTER_R/VOUT-: P105.3, R714.2
/LRCLK_1: P101.5, U101.3
/LRCLK_2: U101.14, U104.6
/SRC_MCLK: U102.5, U104.2
/~RST: U103.1, U104.13
DGND: C102.2, C103.2, C104.2, C105.2, C106.2, C107.2, C201.2, C203.2, C301.2, C302.2, C303.2, C304.2, C305.2, C306.2, C307.2, C308.2, C309.2, C310.2, C311.2, C312.2, C401.2, C402.2, C403.2, C404.2, C405.2, C406.2, C407.2, C408.2, C409.2, C410.2, C411.2, C412.2, C501.2, C503.2, C601.2, C602.1, C603.2, C604.1, C701.2, C702.1, C703.2, C704.1, D104.2, D105.1, P102.2, P103.2, P104.1, P105.1, R103.2, R201.2, R301.2, R401.2, R501.2, U101.9, U101.15, U102.4, U103.3, U104.1, U104.8, U104.9, U104.11, U104.12, U104.16, U104.17, U104.18, U104.20, U104.21, U104.28, U201.2, U301.4, U301.7, U301.10, U301.14, U301.19, U301.26, U301.27, U401.4, U401.7, U401.10, U401.14, U401.19, U401.24, U401.26, U401.27, U501.3, U501.6, U501.7, U601.2, U602.2, U701.2, U702.2, X101.2
GNDA: C101.2, P101.8, R101.2, R102.2, U101.2, U101.8
unnamed: C202.2, U201.4
unnamed: C305.1, C306.1, U301.11
unnamed: C309.1, C310.1, U301.18
unnamed: C405.1, C406.1, U401.11
unnamed: C409.1, C410.1, U401.18
unnamed: C502.2, U501.4
unnamed: C607.1, R601.2, R603.1
unnamed: C607.2, R602.2, R604.1
unnamed: C608.1, R607.2, R609.1
unnamed: C608.2, R608.2, R610.1
unnamed: C707.1, R701.2, R703.1
unnamed: C707.2, R702.2, R704.1
unnamed: C708.1, R707.2, R709.1
unnamed: C708.2, R708.2, R710.1
unnamed: D101.1, P101.1
unnamed: D101.2, R101.1
unnamed: D102.2, R102.1
unnamed: D103.1, U104.14, U104.15
unnamed: D103.2, R103.1
unnamed: D104.1, R104.2
unnamed: D105.2, R105.1
unnamed: D201.2, R201.1
unnamed: D301.1, U301.21
unnamed: D301.2, R301.1
unnamed: D401.1, U401.21
unnamed: D401.2, R401.1
unnamed: D501.2, R501.1
unnamed: R603.2, R605.1, U601.8
unnamed: R604.2, R606.1, U601.1
unnamed: R605.2, R607.1, U601.5
unnamed: R606.2, R608.1, U601.4
unnamed: R609.2, R611.1, U602.8
unnamed: R610.2, R612.1, U602.1
unnamed: R611.2, R613.1, U602.5
unnamed: R612.2, R614.1, U602.4
unnamed: R703.2, R705.1, U701.8
unnamed: R704.2, R706.1, U701.1
unnamed: R705.2, R707.1, U701.5
unnamed: R706.2, R708.1, U701.4
unnamed: R709.2, R711.1, U702.8
unnamed: R710.2, R712.1, U702.1
unnamed: R711.2, R713.1, U702.5
unnamed: R712.2, R714.1, U702.4
unnamed: U102.1, X101.3
VAA: C101.1, D102.1, P101.9, U101.1
VCC: C102.1, C104.1, C202.1, C203.1, D201.1, U102.6, U201.5, X101.1, X101.4
VDD: C103.1, C105.1, C106.1, C107.1, C301.1, C302.1, C401.1, C402.1, C501.1, C502.1, D501.1, U101.10, U101.16, U103.2, U104.7, U104.10, U104.19, U104.22, U104.26, U104.27, U301.6, U301.8, U301.23, U301.24, U301.25, U301.28, U401.6, U401.8, U401.23, U401.25, U401.28, U501.1, U501.2

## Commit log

2014-10-29 added libraries and projects folders
    [DAC.sch, DAC_L.sch, DAC_R.sch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]
2014-11-01 added led_gosselin.lib; removed irrelevant *.lib files
2014-11-01 updated LED indicators in schematic files (*.sch)
    [DAC_L.sch, DAC_R.sch, clock_power.sch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]
2014-11-02 updated LEDs in schematic, output connectors, re-annotated
    [DAC_L.sch, DAC_R.sch, clock_power.sch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]
2014-11-02 updated power sheets
    [clock_power.sch, digital_power.sch, mStereo2.sch]
2014-11-03 updated cvpcb footprint/component links
    [clock_power.sch, digital_power.sch, mStereo2.sch]
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2014-11-09 add MSOP-8 SOIC-16 and TSSOP-28 footprints
2014-11-11 regorganize location of built-in libs and *.sch cleanup in /projects
    [DAC_L.sch, DAC_R.sch, clock_power.sch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]
2014-11-13 add more SMD IC footprints
2014-11-26 update XLR connector part. Netlist now outdated.
    [DAC_L.sch, DAC_R.sch, clock_power.sch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]
2014-11-30 update netlist after changing to new XLR connectors
2014-11-30 add new footprints for discrete R, C, LED and update lib table
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2014-11-30 update schematic notes
    [mStereo2.sch]
2014-12-06 updated notes with mating connector part numbers
    [mStereo2.sch]
2014-12-08 add box cap and small electrolytic cap footprints
    [DAC_L.sch, DAC_R.sch, clock_power.sch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]
2014-12-12 add connector footprints; change c_pol sch symbols
    [filter.sch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]
2014-12-17 Add key PCB and assembly dimensions in a table
2015-02-01 add equations into filter .sch sheets
    [filter.sch]
2015-02-01 remove filter.sch and mStereo2.pro to avoid merge conflict
    [filter.sch]
2015-02-01 add pdf of schematic sheet
2015-02-01 add .png version of schematic
2015-02-01 change schematic image to ,jpg format
2015-02-01 Added schematic in .jpg format in-line
2015-02-01 Add BOM to README
2015-02-01 Fix refs in BOM table
2015-02-03 re-add netlist, correct part numbers
    [DAC_L.sch, DAC_R.sch, clock_power.sch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]
2015-02-03 re-re-annotate to remove lowercase
    [DAC_L.sch, DAC_R.sch, clock_power.sch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]
2015-02-15 imported netlist to PcbNew, drew board outline and set origin
    [mStereo2.kicad_pcb]
2015-02-16 prelimiary component positioning, board resizing, added mounting holes footprint
    [DAC_L.sch, DAC_R.sch, clock_power.sch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]
2015-02-22 secondary part positioning (DAC, filters)
    [mStereo2.kicad_pcb]
2015-03-07 add mfg. spec. info; add dwg. info to sheet text feilds
    [mStereo2.kicad_pcb]
2015-06-17 reposition parts, start routing, add notes for next rev. changes to /doc folder
    [mStereo2.kicad_pcb]
2015-06-18 more routing: reached about 50% completion
    [mStereo2.kicad_pcb]
2015-06-19 more routing; reached 75% completion
    [mStereo2.kicad_pcb]
2015-06-21 more routing and component placement revision
    [mStereo2.kicad_pcb]
2015-06-23 more routing and 3v3 power component placement
    [mStereo2.kicad_pcb]
2015-06-27 place and route all LEDs; append to future additions list
    [mStereo2.kicad_pcb]
2015-07-14 add dimensions, begin repositioning silkscreen reference numbers and component values
    [mStereo2.kicad_pcb]
2015-07-18 rearrage silkscreen
    [mStereo2.kicad_pcb]
2015-07-19 finalize silkscreen, ran DRC, did layer-by-layer visual sanity-check
    [mStereo2.kicad_pcb]
2015-07-22 generate and check gerbers and excellon file
    [mStereo2-B_Cu.gbl, mStereo2-B_Inner_Cu.gbr, mStereo2-B_Mask.gbs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]
2015-07-24 final changes to top silkscreen layout
    [mStereo2.kicad_pcb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]
2015-07-31 fix errors reported by fab (hole spacing too close; 5 places), generate new set of gerbers for resubmission
    [mStereo2-B_Cu.gbl, mStereo2-B_Inner_Cu.gbr, mStereo2-B_Mask.gbs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]
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2015-08-08 Add missing references R401, R301 to BOM
2015-08-08 update vendor name spelling and references in BOM
2015-08-08 update missing quantity for RNCP0805FTD121RCT-ND in BOM
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2015-08-08 add a .CSV copy of the BOM
    [mStereo2.csv]
2015-08-08 fix number of columns in row 9
    [mStereo2.csv]
2015-08-08 Update link to .csv bom instead of bom readme
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2015-08-12 fix repeated line entry in BOM
    [mStereo2.csv]
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2015-08-12 split assembly information out into a separate doc
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2015-08-12 make partial BOMs for each vendor for easy ordering
    [mStereo2_partial_digikey.csv, mStereo2_partial_mouser.csv]
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2015-09-10 fix erroneous 1.21KOhm resistor digi-key-part-number (previously used a p/n for a 1kOhm resistor)
    [mStereo2.csv, mStereo2_partial_digikey.csv]
2015-10-18 update BOM so most parts (all but one) are sourced from digi-key
    [mStereo2.csv, mStereo2_partial_digikey.csv, mStereo2_partial_mouser.csv]
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2015-10-23 add chassis assembly info to BOM notes for now
2015-11-09 adding first drafts of power supplies and accessories BOMs
    [s22.csv]
2015-11-09 update trafo info
    [s22.csv]
2015-11-09 update heatsink and connectors for 5V supply
    [5V_supply.csv, e24.csv]
2015-11-09 first commit of e24 BOM with correct P/Ns
    [e24.csv]
2015-11-09 update e24 and s22 part numbers
    [e24.csv, s22.csv]
2015-11-09 finalize power supply boms, ready for ordering
    [5V_supply.csv, e24.csv, s22.csv]
2015-11-09 final part number additions to e24 BOM
    [e24.csv]
2015-11-09 update rectifier part number: previous one was obsolete
    [e24.csv]
2015-11-09 update part number of momentary swtich
    [e24.csv]
2015-11-09 update connector, trafo, power entry part numbers in power supply BOMs
    [5V_supply.csv, s22.csv]
2015-11-09 reorganize AMB BOMs folder
    [TPS7A4700_psu.csv, e24.csv, s22.csv]
2015-11-09 update s22 BOM
    [s22.csv]
2015-11-09 remove broken link to assembly page
2015-11-09 adding AMB d1 BOM
    [d1.csv]
2015-11-15 finalize d1 BOM
    [d1.csv]
2015-11-16 add LCDuino-1 BOM and update future additions text file
    [LCDuino-1.csv]
2016-01-09 update trafo desc
    [e24.csv]
2016-03-13 updates to AMB power supply BOMs
    [LCDuino-1.csv, d1.csv, e24.csv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]
2016-03-13 fix leftover text left by mergetool
    [d1.csv, e24.csv]
2016-03-13 remove stray errant quotation in e24.csv
    [d1.csv]
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2016-03-16 update s22 heatsink part number
    [s22.csv]
2016-04-16 fix duplicates in BOM
    [mStereo2.csv]

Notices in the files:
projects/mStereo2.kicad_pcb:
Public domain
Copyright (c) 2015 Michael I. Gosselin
